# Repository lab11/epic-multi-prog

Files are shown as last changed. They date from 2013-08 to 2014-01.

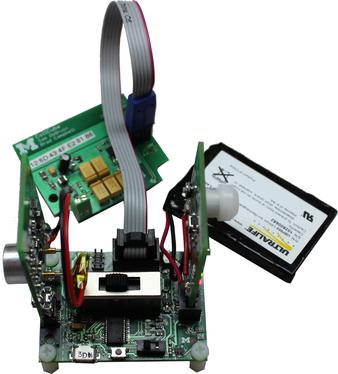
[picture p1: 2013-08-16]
media/epic_multi_prog_connected_338x374.jpg

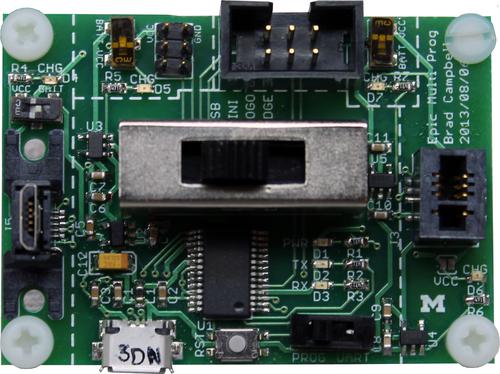
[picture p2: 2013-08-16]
media/epic_multi_prog_500x374.jpg

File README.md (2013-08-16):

Epic Multi Prog
===============

emp (https://raw.github.com/lab11/epic-multi-prog/master/media/epic_multi_prog.jpg)
emp_connected (https://raw.github.com/lab11/epic-multi-prog/master/media/epic_multi_prog_connected.jpg)

Programmer hardware for programming the epic family of devices.
Over the years many different physical connections for programming the epic chip have
been created. This programmer tries to support the common ones:

- Edge style: as used by the Irene family of sensor nodes
- Tag connect (pogo pins): new 6-pin connector from Tag Connect
- Mini prog: 6 pin 2mm connector as used by some epic devices
- Pseudo USB: micro USB connector that also uses the shield for some epic devices

All connection types have their own charging module and charging LED. The center switch
selects which header is connected to the programming lines and therefore which one should
be programmed. The board connects to a computer via a micro USB cable.

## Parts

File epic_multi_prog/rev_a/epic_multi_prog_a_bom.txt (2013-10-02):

# Bill of Materials
# Converted from epic_multi_prog_a_bom.xls
# Generated by bom_to_text.py

Qty  Value                              Device                             Package                            Parts                             Description                                            DIGIKEY            MOUSER         DIGIREEL
3    0.1u                               C-EUC0603                          C0603                              C1, C2, C3                        CAPACITOR, European symbol                             445-1316-1-ND                     445-1316-6-ND
8    1u                                 C-EUC0603                          C0603                              C4, C5, C6, C7, C8, C9, C10, C11  CAPACITOR, European symbol                             445-1321-1-ND                     445-1321-6-ND
1    10u                                CAP_POL1206                        EIA3216                            C12                               Capacitor Polarized                                    478-1655-1-ND                     478-1655-6-ND
1    BLUE                               LED0603                            LED-0603                           D1                                LEDs                                                   160-1837-1-ND                     160-1837-6-ND
1    RED                                LED0603                            LED-0603                           D2                                LEDs                                                   160-1835-1-ND                     160-1835-6-ND
1    GREEN                              LED0603                            LED-0603                           D3                                LEDs                                                   160-1834-1-ND                     160-1834-6-ND
4    YELLOW                             LED0603                            LED-0603                           D4, D5, D6, D7                    LEDs                                                   160-1184-1-ND                     160-1184-6-ND
1    EPIC-PROG-PORT                     EPIC-PROG-PORT                     HEADER2X3X2MM                      J1                                                                                       3M9173-ND                         
1    MICRO_USB_B_HIROSE_ZX62R-B-5P      MICRO_USB_B_HIROSE_ZX62R-B-5P      USB_MICRO_B-HIROSE-ZX62R-B-5P      J2                                USB Micro B Connector                                  H11574CT-ND                       H11574DKR-ND
1    MEC1-105-02-XX-XX-D-A              MEC1-105-02-XX-XX-D-A              MEC1-105-02-XX-XX-D-A              J3                                                                                       SAM8115-ND                        
1    TAG_CONNECT_HEADER_EPIC            TAG_CONNECT_HEADER_EPIC            2X3_MALE_SHROUDED_0.100            J4                                2x3 Male Shrouded Header 0.100                         3M15451-ND                        
1    MICRO_USB_B_MALE_HIROSE_ZX80-B-5S  MICRO_USB_B_MALE_HIROSE_ZX80-B-5S  USB_MICRO_B_MALE-HIROSE-ZX80-B-5S  J5                                CONN PLUG MCR USB B PCB VERT                           H11612-ND          798-ZX80-B-5S  
1                                       INDUCTOR0603                       603                                L1                                Inductors                                              240-2373-1-ND                     240-2373-6-ND
7    470                                R-US_R0603                         R0603                              R1, R2, R3, R4, R5, R6, R7        RESISTOR, American symbol                              P470GDKR-ND                       P470GDKR-ND
1    TE_SSA12/SPDT                      TE_SSA12/SPDT                      TE_SSA12/SPDT                      S1                                SWITCH SLIDE SPDT 2POS SSA SER                         450-1602-ND                       
1    CK_SS-44D04-G4/4P4T                CK_SS-44D04-G4/4P4T                CK_SS-44D04-G4/4P4T                S2                                Through hole 4P4T switch.                              CKN10389-ND                       
1    EVQP2                              EVQP2                              EVQP2                              S3                                                                                       P11084SCT-ND                      
3    COPAL_CJS-1200TA/SPDT              COPAL_CJS-1200TA/SPDT              COPAL_CJS-1200TA/SPDT              S4, S5, S6                        SWITCH SLIDE SPDT SMD J-LEAD                           563-1021-2-ND                     563-1021-6-ND
1    FT232RL                            FT232RL                            SSOP28                             U1                                FTDI chip                                              768-1007-1-ND                     768-1007-6-ND
4    MAX1555                            MAX1555                            SOT23-5L                           U2, U3, U4, U5                    Dual-Input USB/AC Adapter 1-Cell Li+ Battery Chargers  MAX1555EZK+TCT-ND                 MAX1555EZK+TDKR-ND

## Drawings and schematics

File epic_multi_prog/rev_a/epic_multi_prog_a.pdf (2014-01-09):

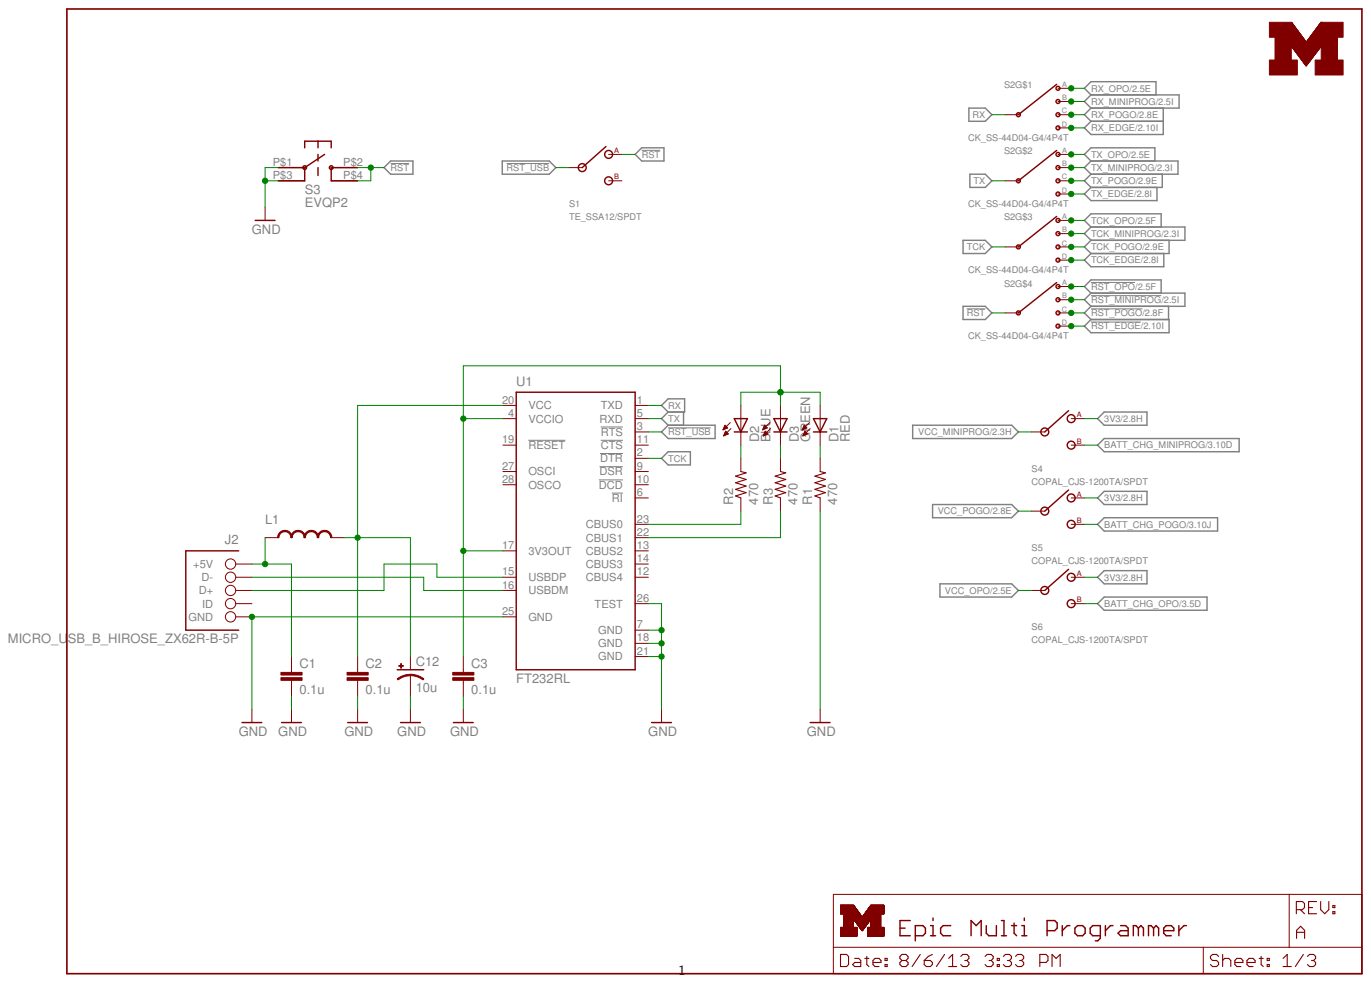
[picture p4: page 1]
GND 0.1u; 0.1u GND GND; GND; 470 BLUE; GREEN EVQP2 GND; RED 470 GND; CK_SS-44D04-G4/4P4T CK_SS-44D04-G4/4P4T CK_SS-44D04-G4/4P4T CK_SS-44D04-G4/4P4T COPAL_CJS-1200TA/SPDT COPAL_CJS-1200TA/SPDT COPAL_CJS-1200TA/SPDT TE_SSA12/SPDT U1VCC 20; 3V3OUT 17; USBDP 15; USBDM 16; OSCO 28; OSCI 27; 7 TXD; 1 RXD; 5 RTS; 3 CTS; 11 DTR; 2 DSR; 9 DCD; 6 CBUS0; 23 CBUS1; 22 CBUS2; 13 CBUS3; 14 CBUS4; 12 VCCIO 4; RESET 19; GND 25; 18 TEST; 26 GND; P$4 J2 MICRO_USB_B_HIROSE_ZX62R-B-5P ⁺⁵VD- D+ID GND; ABCD S2G$1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

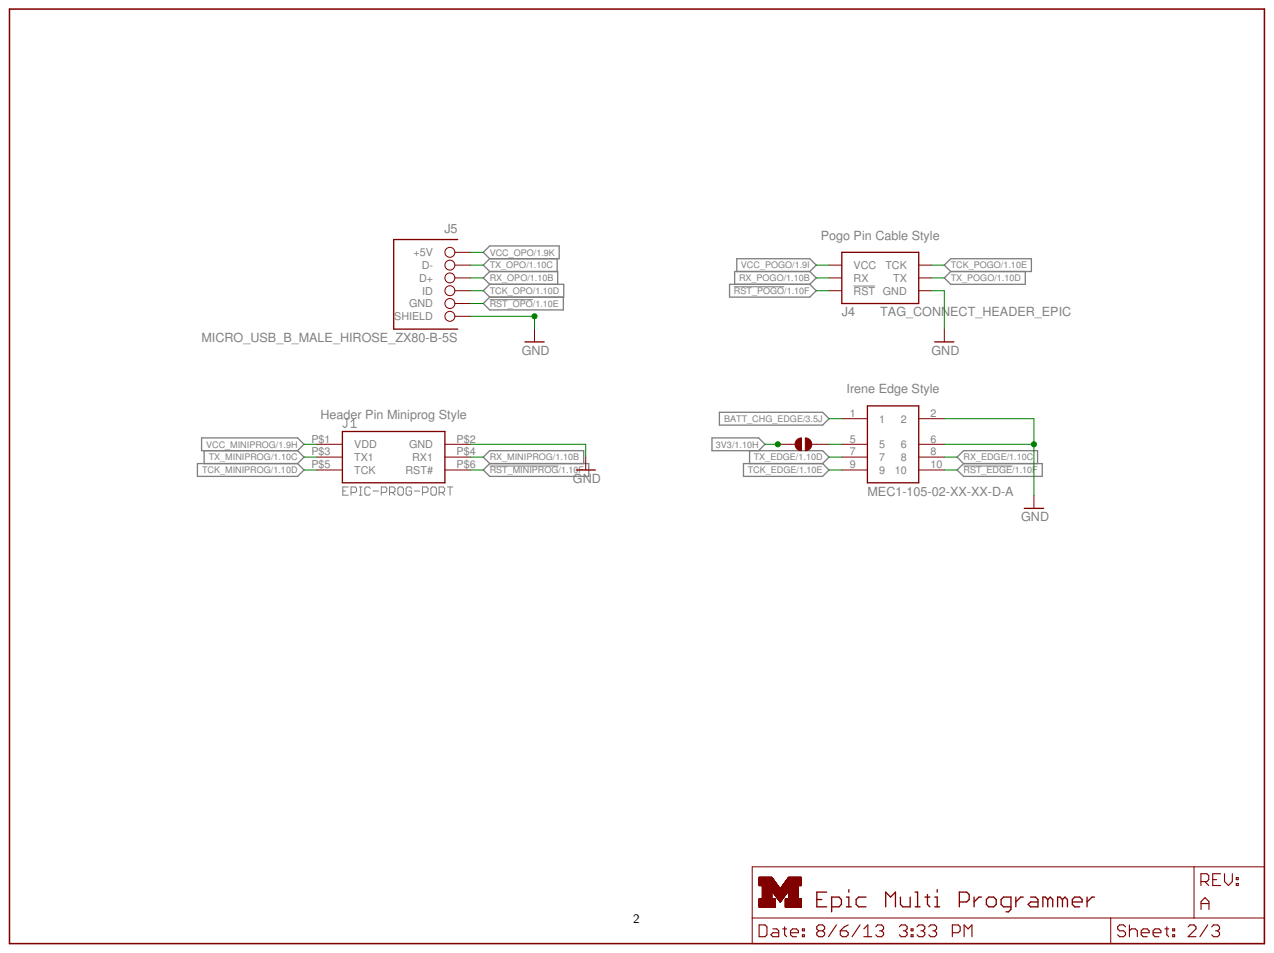
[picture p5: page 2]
MEC1-105-02-XX-XX-D-A; GND; TAG_CONNECT_HEADER_EPIC; VDD; P$1 TX1 P$3 TCK; RST#; P$4 GND; VCC RX RST; TCK TX GND; MICRO_USB_B_MALE_HIROSE_ZX80-B-5S; ID GND SHIELD; TX_MINIPROG/1.10C; TX_EDGE/1.10D; TX_POGO/1.10D; TX_OPO/1.10C; RX_OPO/1.10B; RX_POGO/1.10B; RX_MINIPROG/1.10B; RX_EDGE/1.10C; RST_OPO/1.10E; TCK_MINIPROG/1.10D; TCK_EDGE/1.10E; TCK_POGO/1.10E; TCK_OPO/1.10D; RST_MINIPROG/1.10F; RST_EDGE/1.10F; RST_POGO/1.10F VCC_OPO/1.9K VCC_POGO/1.9I; VCC_MINIPROG/1.9H; BATT_CHG_EDGE/3.5J

Pogo Pin Cable Style

Irene Edge Style Header Pin Miniprog Style

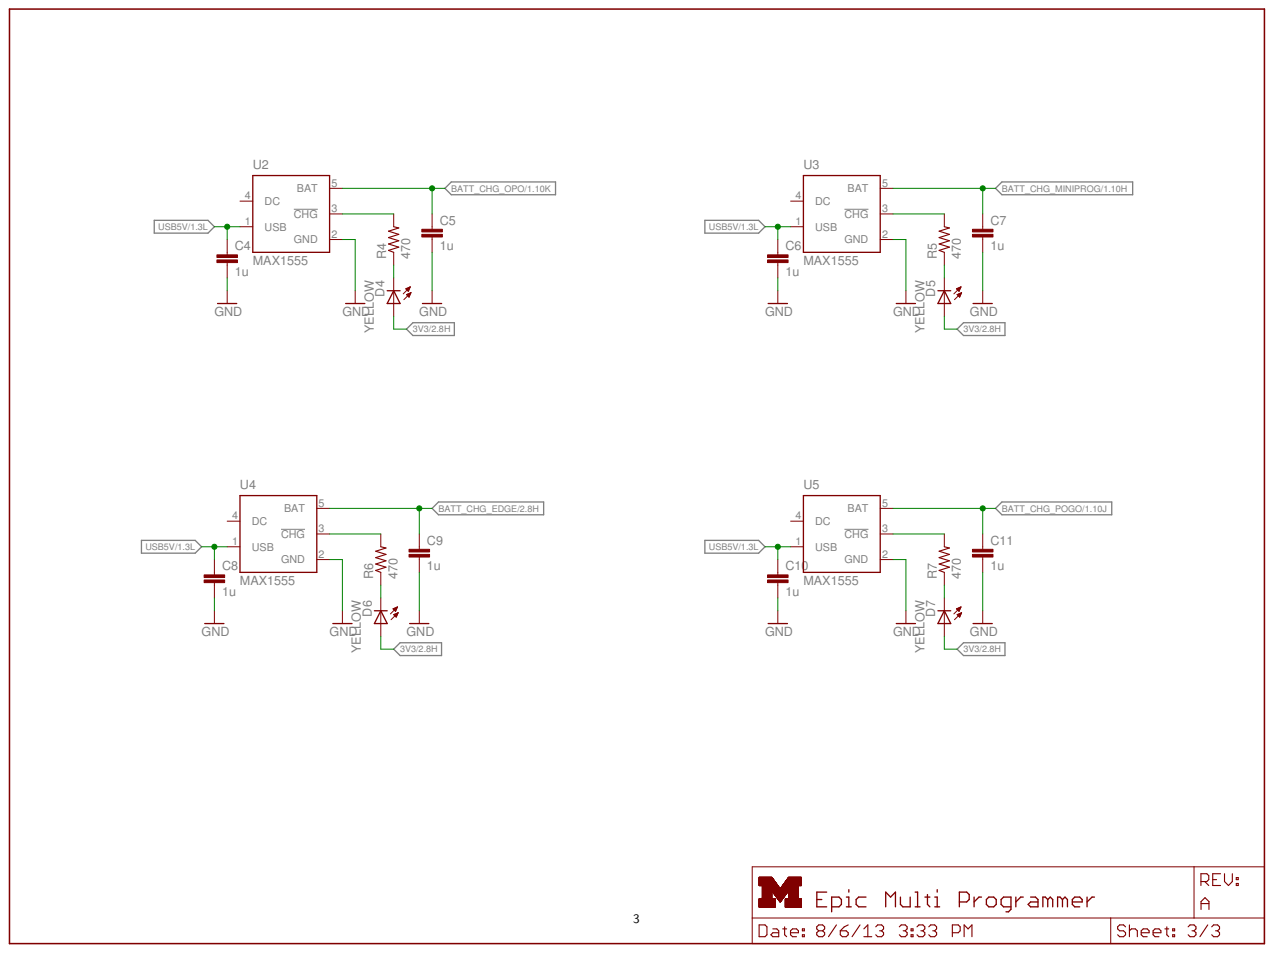
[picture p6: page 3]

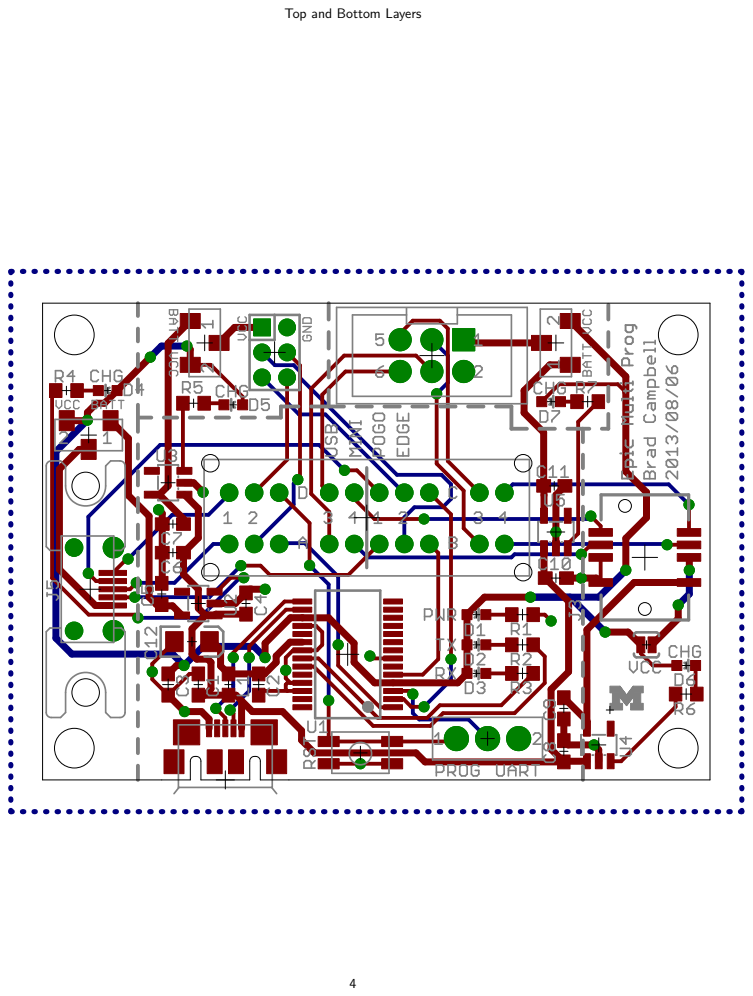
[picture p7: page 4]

Top and Bottom Layers

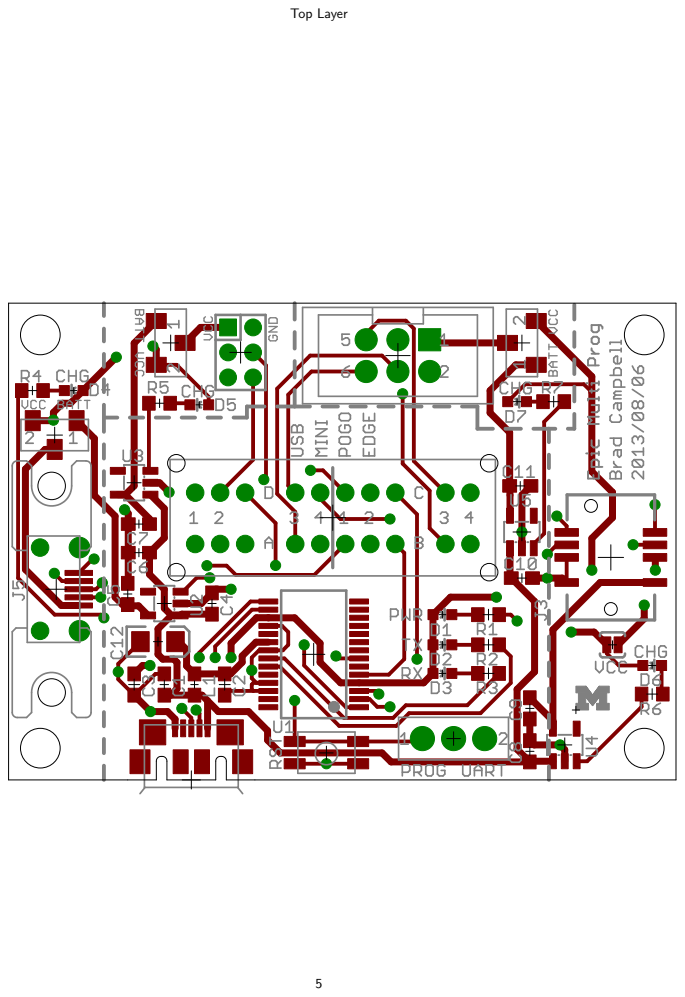
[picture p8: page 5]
Top Layer

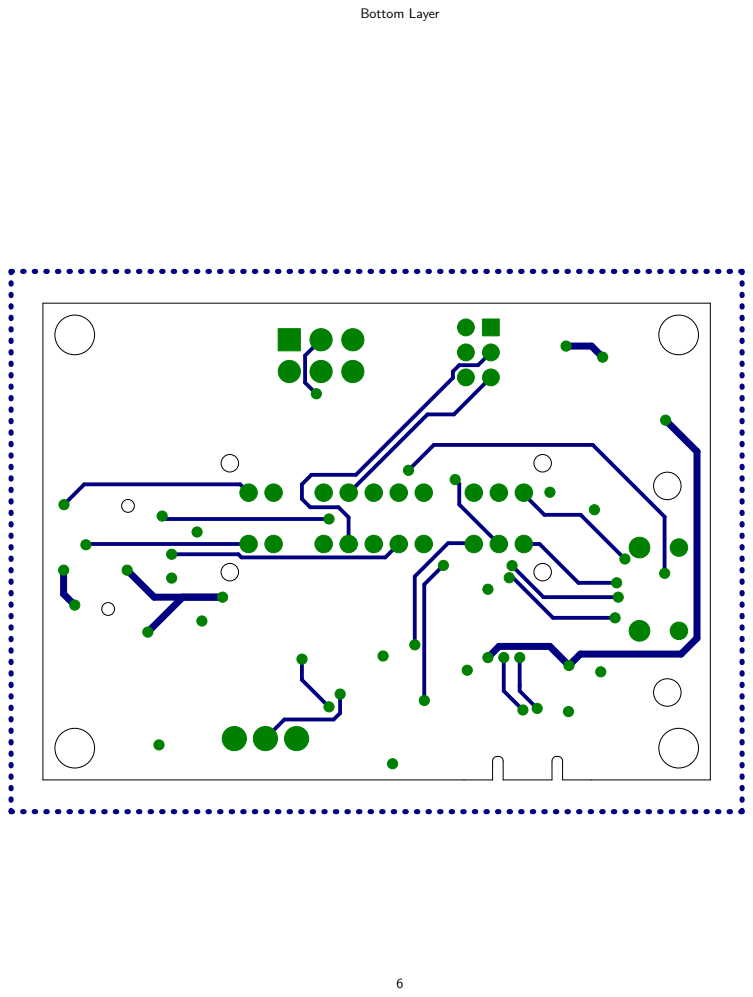
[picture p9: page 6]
Bottom Layer

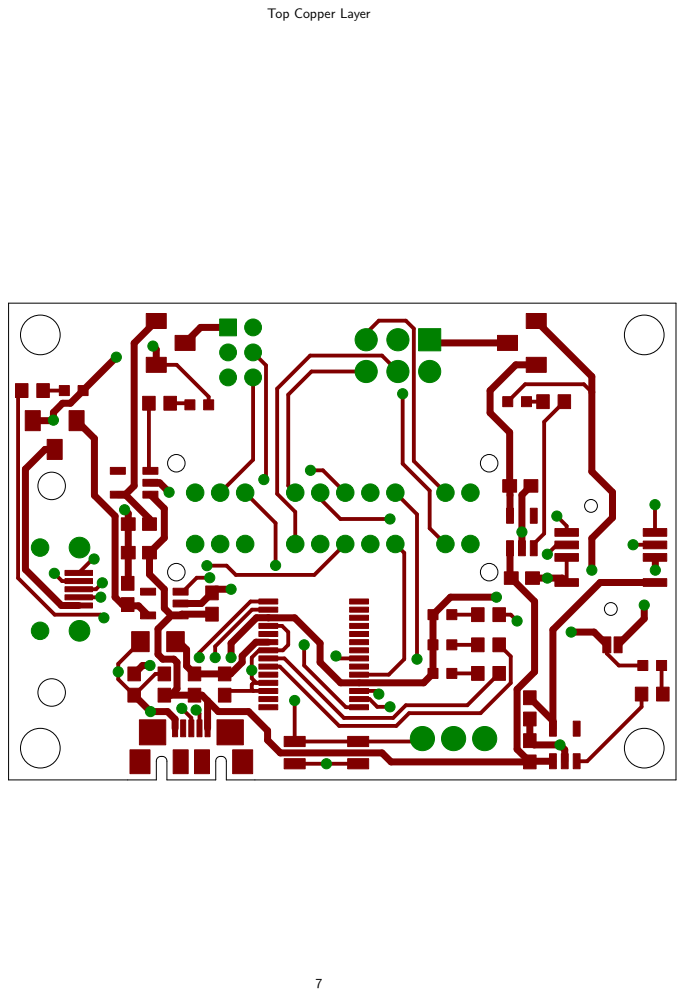
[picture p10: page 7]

Top Copper Layer

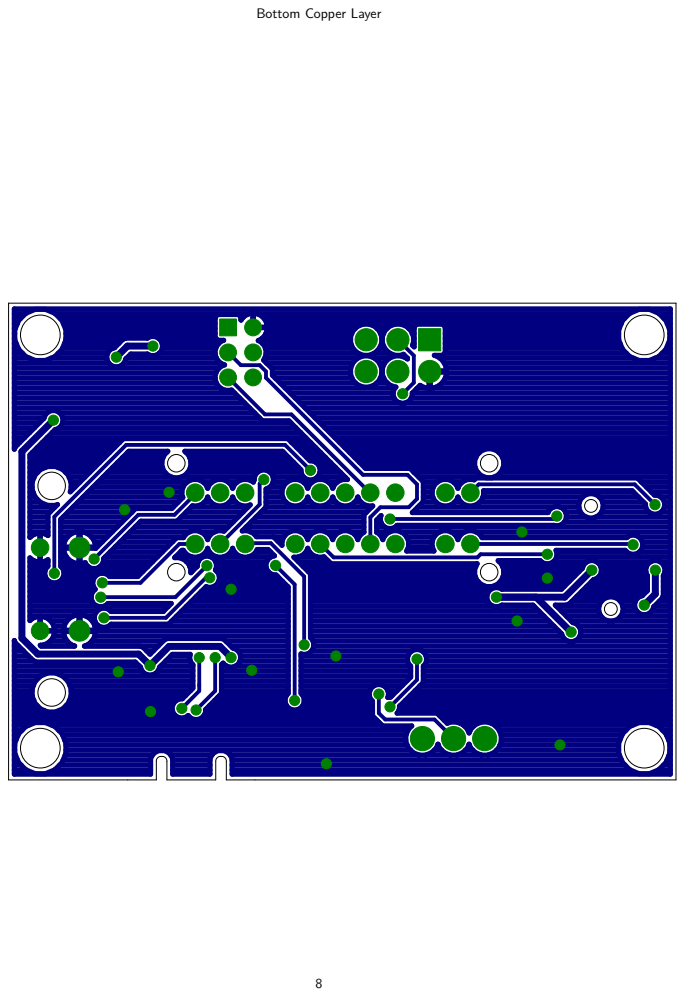
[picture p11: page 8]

Bottom Copper Layer

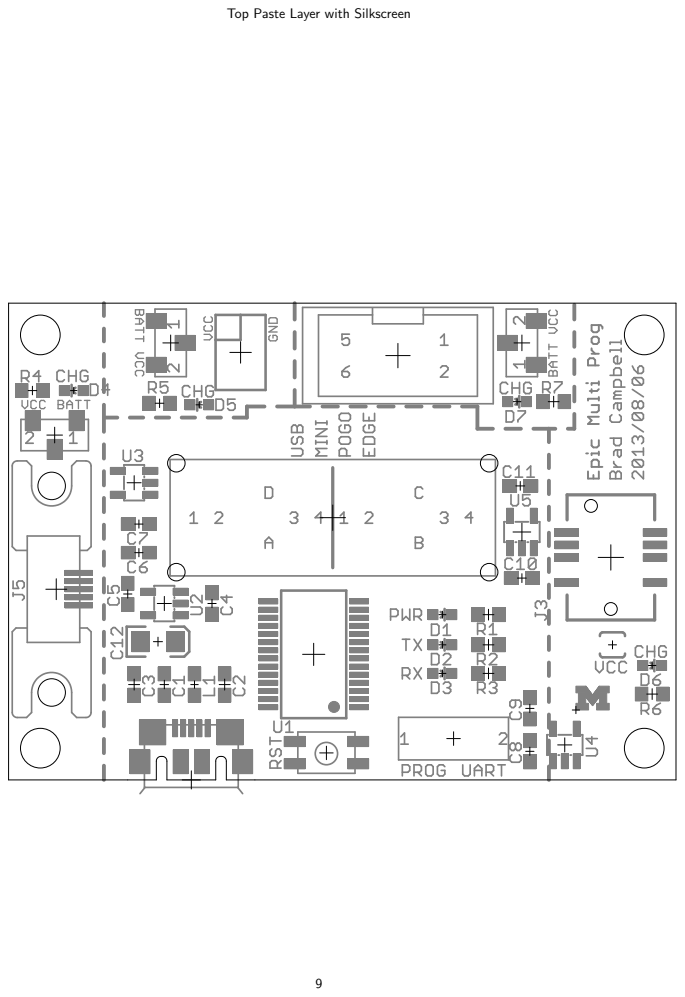
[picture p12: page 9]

Top Paste Layer with Silkscreen

Bottom Paste Layer with Silkscreen

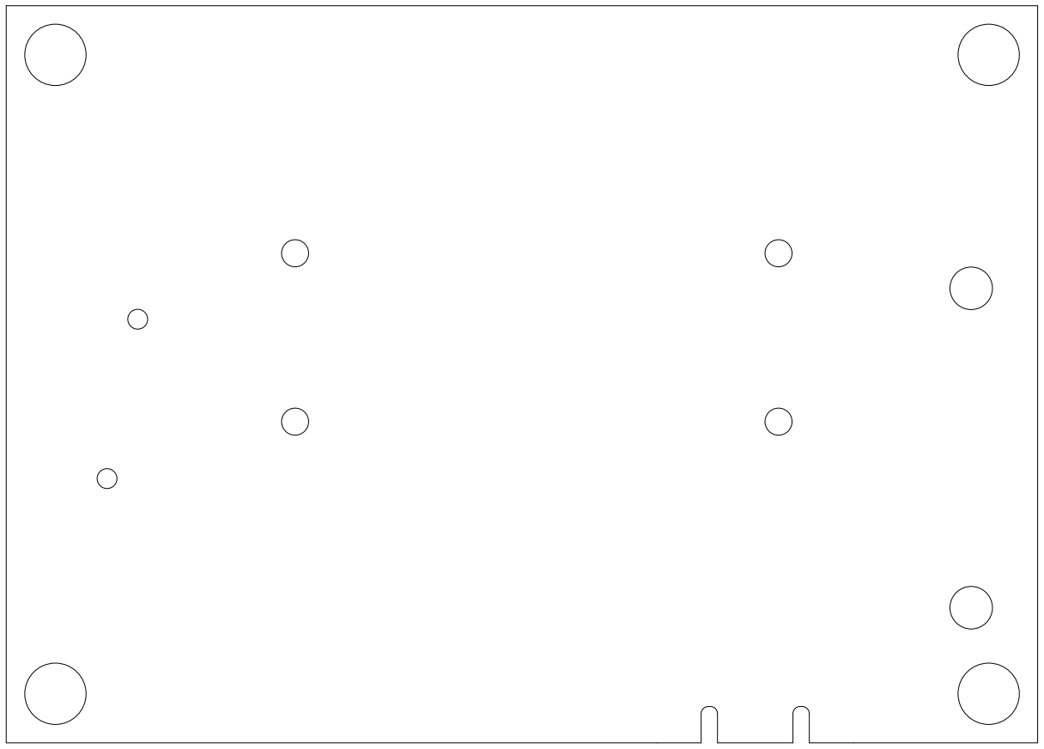
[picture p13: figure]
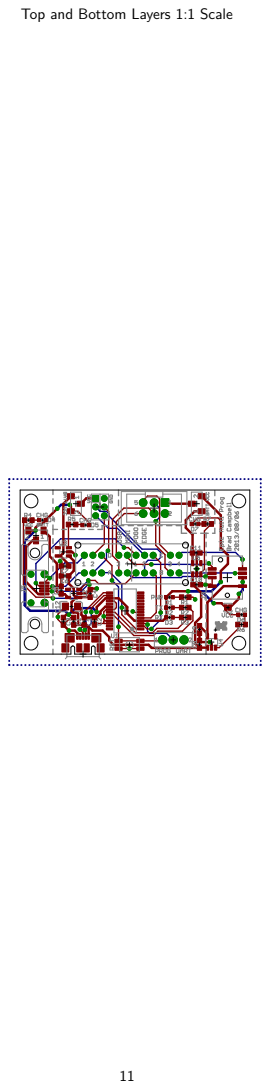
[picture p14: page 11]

Top and Bottom Layers 1:1 Scale

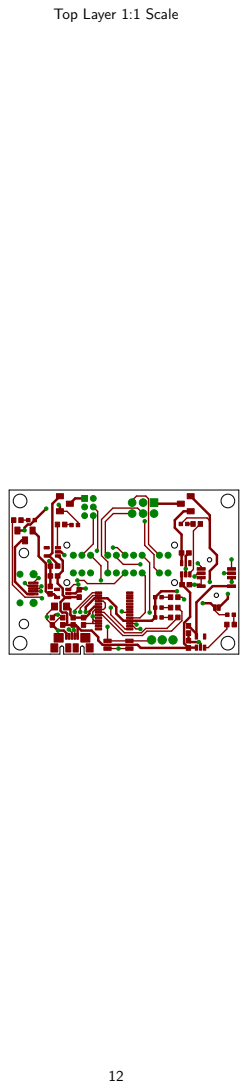
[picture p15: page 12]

Top Layer 1:1 Scale


Bottom Copper Layer 1:1 Scale

### Sheet1

Qty Value | Device
3 0.1u | C-EUC0603
8 1u | C-EUC0603
1 10u | CAP_POL1206
1 BLUE | LED0603
1 RED | LED0603
1 GREEN | LED0603
4 YELLOW | LED0603
1 EPIC-PROG-PORT | EPIC-PROG-PORT
1 MICRO_USB_B_HIROSE_ZX62R-B-5P | MICRO_USB_B_HIROSE_ZX62R-B-5P
1 MEC1-105-02-XX-XX-D-A | MEC1-105-02-XX-XX-D-A
1 TAG_CONNECT_HEADER_EPIC | TAG_CONNECT_HEADER_EPIC
1 MICRO_USB_B_MALE_HIROSE_ZX80-B-5S MICRO_USB_B_MALE_HIROSE_ZX80-B-5S
1 | INDUCTOR0603
7 470 | R-US_R0603
1 TE_SSA12/SPDT | TE_SSA12/SPDT
1 CK_SS-44D04-G4/4P4T | CK_SS-44D04-G4/4P4T
1 EVQP2 | EVQP2
3 COPAL_CJS-1200TA/SPDT | COPAL_CJS-1200TA/SPDT
1 FT232RL | FT232RL
4 MAX1555 | MAX1555

### Sheet1

Package | Parts
C0603 | C1, C2, C3
C0603 | C4, C5, C6, C7, C8, C9, C10, C11
EIA3216 | C12
LED-0603 | D1
LED-0603 | D2
LED-0603 | D3
LED-0603 | D4, D5, D6, D7
HEADER2X3X2MM | J1
USB_MICRO_B-HIROSE-ZX62R-B-5P | J2
MEC1-105-02-XX-XX-D-A | J3
2X3_MALE_SHROUDED_0.100 | J4
USB_MICRO_B_MALE-HIROSE-ZX80-B-5S J5
603 | L1
R0603 | R1, R2, R3, R4, R5, R6, R7
TE_SSA12/SPDT | S1
CK_SS-44D04-G4/4P4T | S2
EVQP2 | S3
COPAL_CJS-1200TA/SPDT | S4, S5, S6
SSOP28 | U1
SOT23-5L | U2, U3, U4, U5

### Sheet1

Description | DIGIKEY | MOUSER
CAPACITOR, European symbol | 445-1316-1-ND
CAPACITOR, European symbol | 445-1321-1-ND
Capacitor Polarized | 478-1655-1-ND
LEDs | 160-1837-1-ND
LEDs | 160-1835-1-ND
LEDs | 160-1834-1-ND
LEDs | 160-1184-1-ND
| 3M9173-ND
USB Micro B Connector | H11574CT-ND
| SAM8115-ND
2x3 Male Shrouded Header 0.100 | 3M15451-ND
CONN PLUG MCR USB B PCB VERT | H11612-ND | 798-ZX80-B-5S
Inductors | 240-2373-1-ND
RESISTOR, American symbol | P470GDKR-ND
SWITCH SLIDE SPDT 2POS SSA SER | 450-1602-ND
Through hole 4P4T switch. | CKN10389-ND
| P11084SCT-ND
SWITCH SLIDE SPDT SMD J-LEAD | 563-1021-2-ND
FTDI chip | 768-1007-1-ND
Dual-Input USB/AC Adapter 1-Cell Li+ Battery Chargers MAX1555EZK+TCT-ND

### Sheet1

DIGIREEL
445-1316-6-ND
445-1321-6-ND
478-1655-6-ND
160-1837-6-ND
160-1835-6-ND
160-1834-6-ND
160-1184-6-ND

H11574DKR-ND

240-2373-6-ND
P470GDKR-ND

563-1021-6-ND
768-1007-6-ND
MAX1555EZK+TDKR-ND

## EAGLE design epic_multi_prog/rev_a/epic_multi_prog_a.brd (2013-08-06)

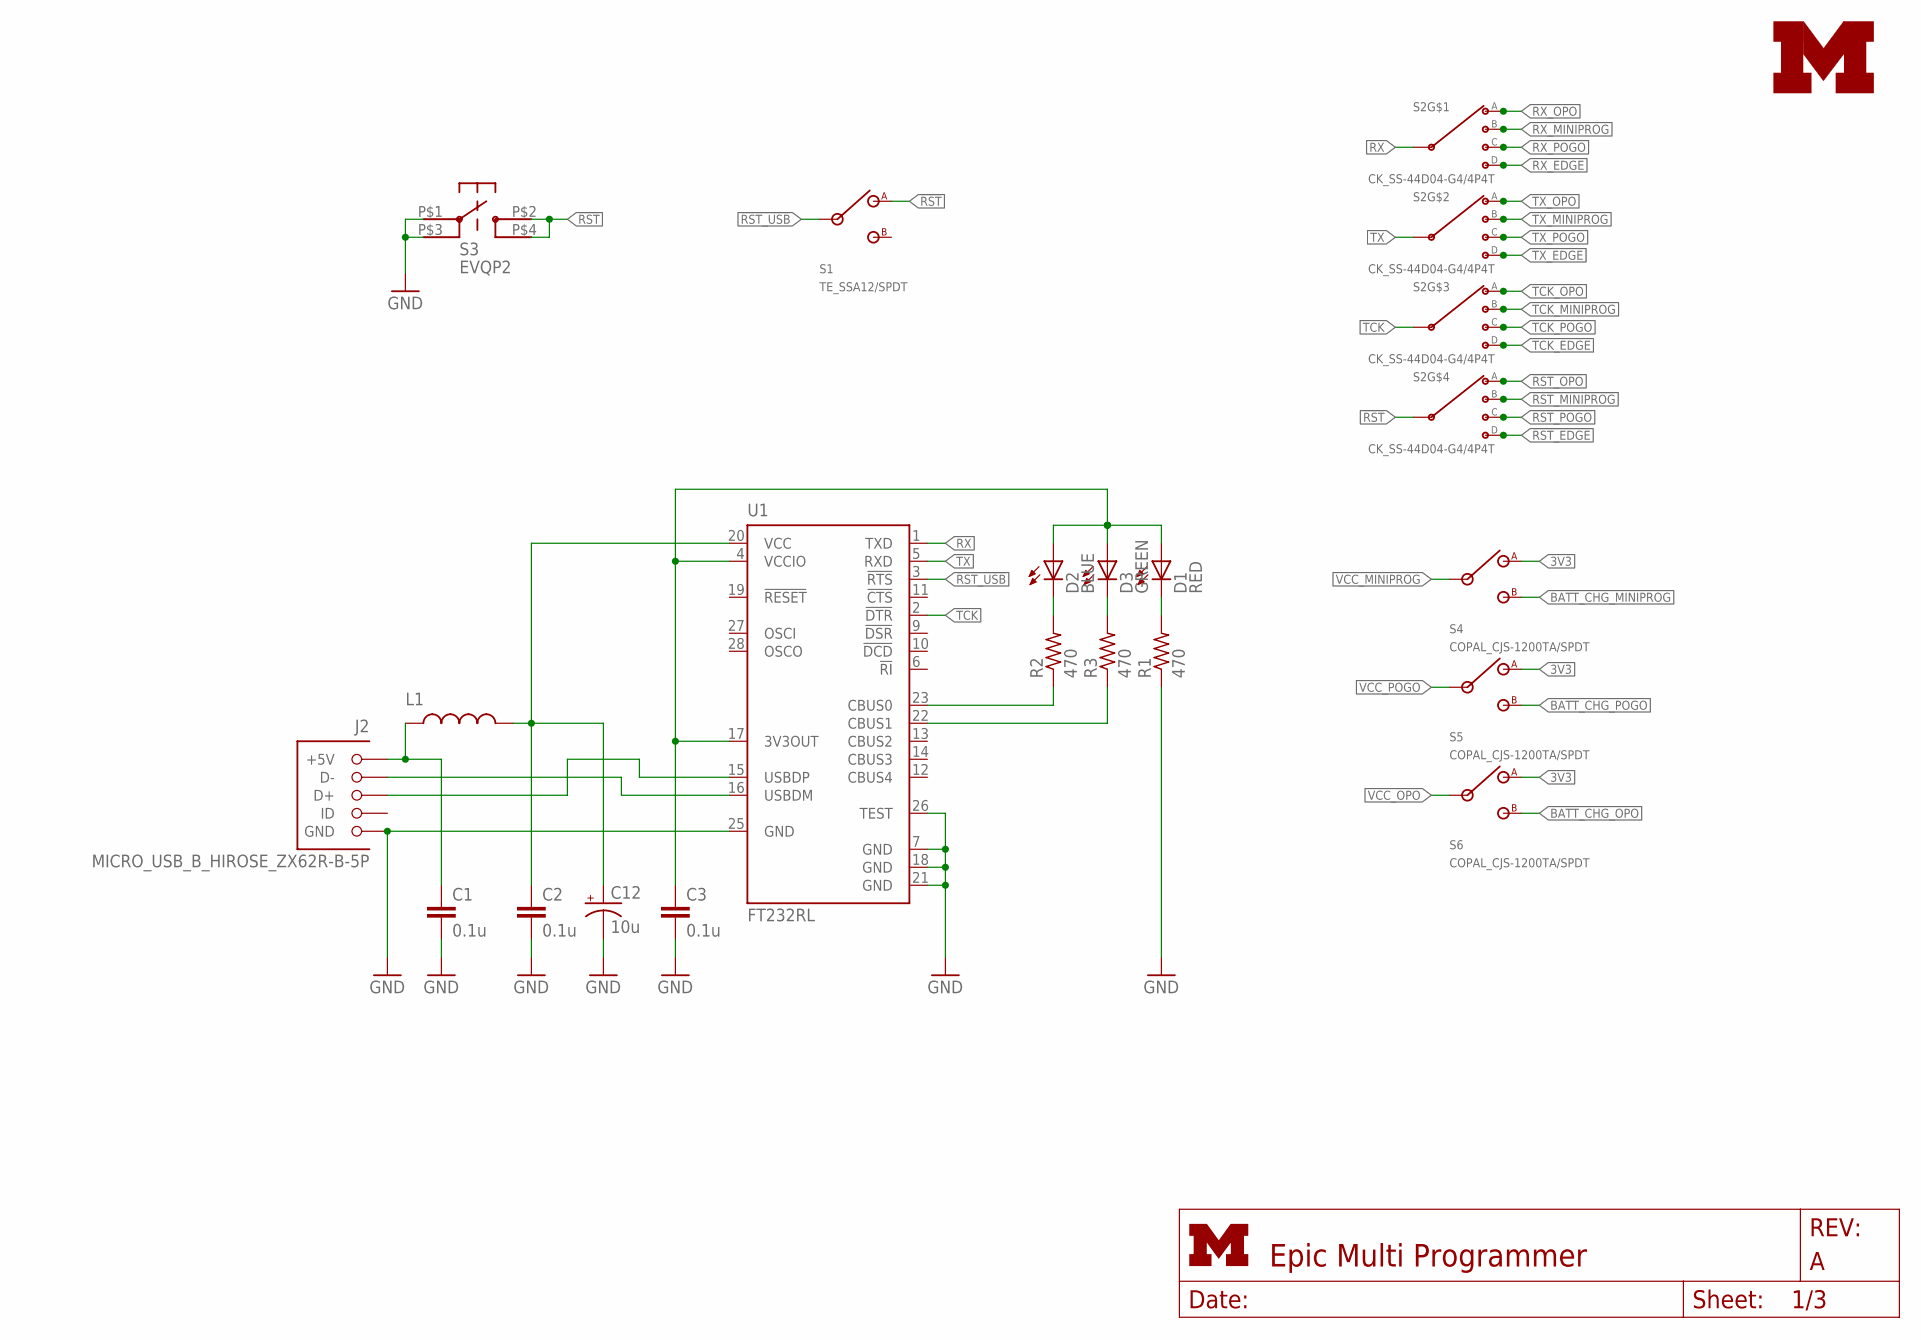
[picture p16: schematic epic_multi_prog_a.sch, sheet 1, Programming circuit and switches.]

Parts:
C1, C2, C3: 0.1u; C0603; DIGIKEY 445-1316-1-ND
C12: 10u; EIA3216; DIGIKEY 478-1655-1-ND
D1: RED; LED-0603
D2: BLUE; LED-0603
D3: GREEN; LED-0603
J2: MICRO_USB_B_HIROSE_ZX62R-B-5P; USB_MICRO_B-HIROSE-ZX62R-B-5P
L1: INDUCTOR0603; 0603; DIGIKEY 240-2373-1-ND
R1, R2, R3: 470; R0603
S1: TE_SSA12/SPDT
S2: CK_SS-44D04-G4/4P4T; DIGIKEY CKN10389-ND
S3: EVQP2; DIGIKEY P11084SCT-ND
S4, S5, S6: COPAL_CJS-1200TA/SPDT
U1: FT232RL; SSOP28; DIGIKEY 768-1007-1-ND
U$1: UMICH_SOLID_SMALL; UMICH_SOLID_75MIL

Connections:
3V3: C3.1, D1.A, D2.A, D3.A, S4.2 (A), S5.2 (A), S6.2 (A), U1.4 (VCCIO), U1.17 (3V3OUT); also elsewhere on the board
!RST: S1.1 (A), S2.IND (INPUT), S3.P$2, S3.P$4
!RST_EDGE: S2.D4 (D); also elsewhere on the board
!RST_MINIPROG: S2.D2 (B); also elsewhere on the board
!RST_OPO: S2.D1 (A); also elsewhere on the board
!RST_POGO: S2.D3 (C); also elsewhere on the board
!RST_USB: S1.IN, U1.3 (!RTS)
BATT_CHG_MINIPROG: S4.1 (B); also elsewhere on the board
BATT_CHG_OPO: S6.1 (B); also elsewhere on the board
BATT_CHG_POGO: S5.1 (B); also elsewhere on the board
GND: C1.2, C2.2, C3.2, C12.C (-), J2.5 (GND), R1.1, S3.P$1, S3.P$3, U1.7 (GND), U1.18 (GND), U1.21 (GND), U1.25 (GND), U1.26 (TEST); also elsewhere on the board
unnamed: D2.C, R2.2
unnamed: J2.2 (D-), U1.16 (USBDM)
unnamed: J2.3 (D+), U1.15 (USBDP)
unnamed: C2.1, C12.A (+), L1.2, U1.20 (VCC)
unnamed: D3.C, R3.2
unnamed: D1.C, R1.2
unnamed: R2.1, U1.23 (CBUS0)
unnamed: R3.1, U1.22 (CBUS1)
RX: S2.INA (INPUT), U1.1 (TXD)
RX_EDGE: S2.A4 (D); also elsewhere on the board
RX_MINIPROG: S2.A2 (B); also elsewhere on the board
RX_OPO: S2.A1 (A); also elsewhere on the board
RX_POGO: S2.A3 (C); also elsewhere on the board
TCK: S2.INC (INPUT), U1.2 (!DTR)
TCK_EDGE: S2.C4 (D); also elsewhere on the board
TCK_MINIPROG: S2.C2 (B); also elsewhere on the board
TCK_OPO: S2.C1 (A); also elsewhere on the board
TCK_POGO: S2.C3 (C); also elsewhere on the board
TX: S2.INB (INPUT), U1.5 (RXD)
TX_EDGE: S2.B4 (D); also elsewhere on the board
TX_MINIPROG: S2.B2 (B); also elsewhere on the board
TX_OPO: S2.B1 (A); also elsewhere on the board
TX_POGO: S2.B3 (C); also elsewhere on the board
USB5V: C1.1, J2.1 (+5V), L1.1; also elsewhere on the board
VCC_MINIPROG: S4.IN; also elsewhere on the board
VCC_OPO: S6.IN; also elsewhere on the board
VCC_POGO: S5.IN; also elsewhere on the board

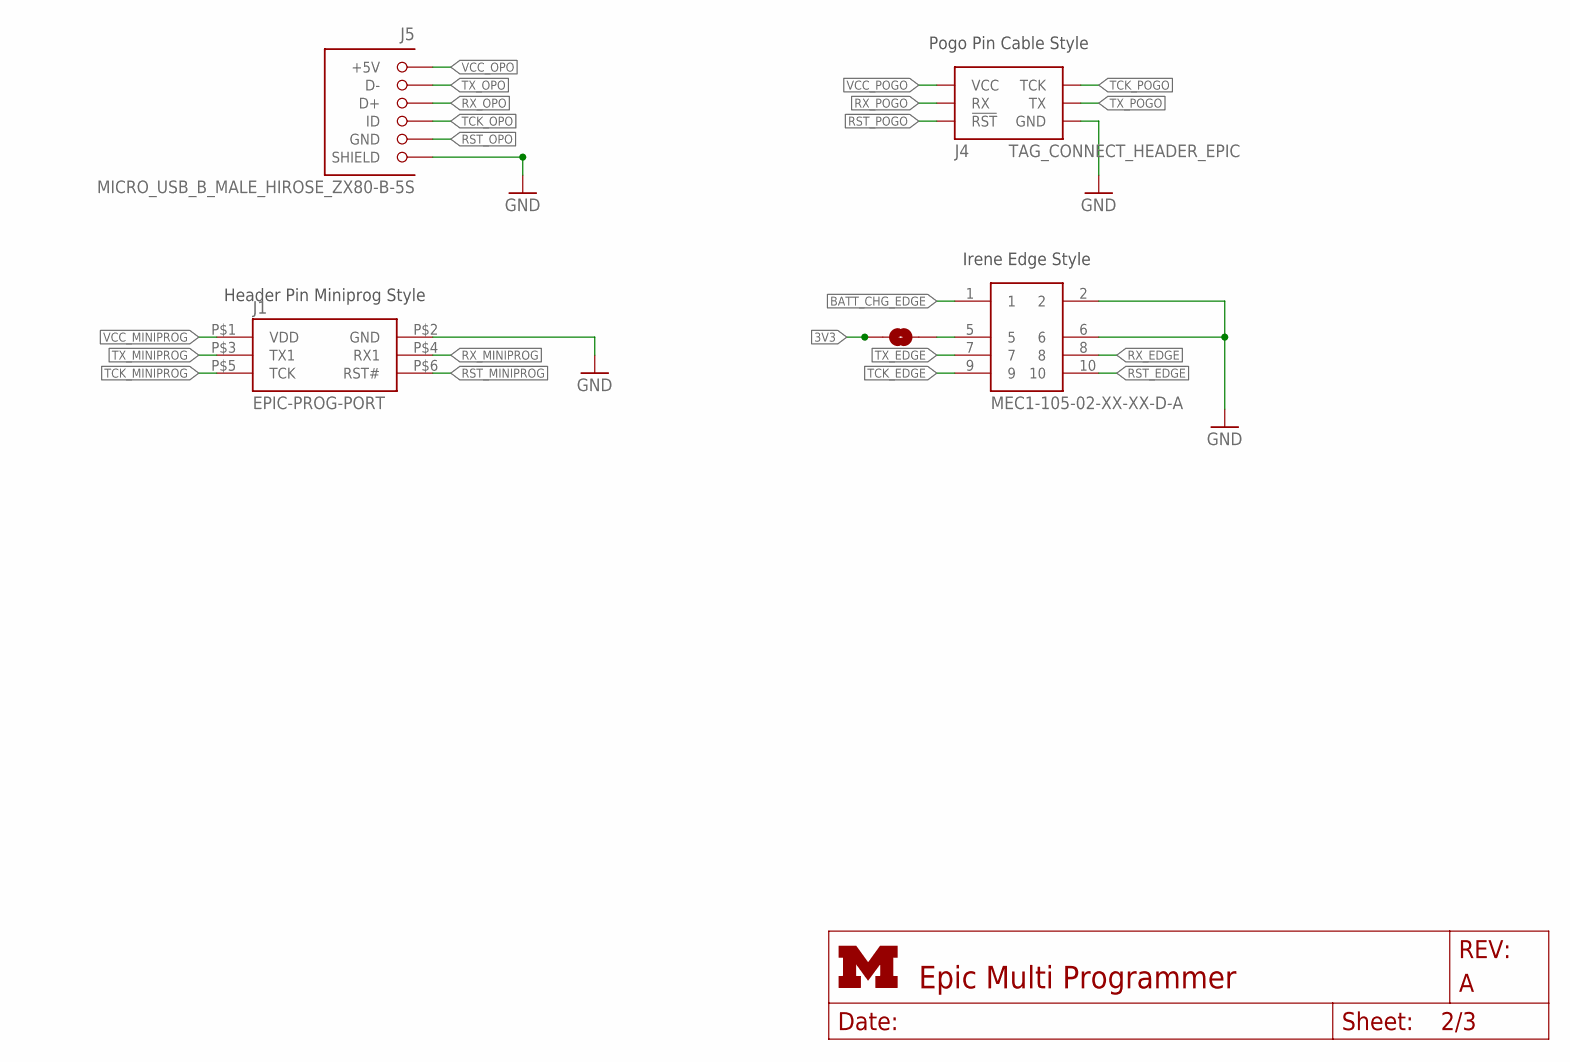
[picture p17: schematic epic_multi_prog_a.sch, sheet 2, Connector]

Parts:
J1: EPIC-PROG-PORT; HEADER2X3X2MM
J3: MEC1-105-02-XX-XX-D-A; DIGIKEY SAM8115-ND
J4: TAG_CONNECT_HEADER_EPIC; 2X3_MALE_SHROUDED_0.100
J5: MICRO_USB_B_MALE_HIROSE_ZX80-B-5S; USB_MICRO_B_MALE-HIROSE-ZX80-B-5S; MOUSER 798-ZX80-B-5S
SJ1: SOLDERJUMPERNO; SJ_2S-NO

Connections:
3V3: SJ1.1; also elsewhere on the board
!RST_EDGE: J3.10; also elsewhere on the board
!RST_MINIPROG: J1.P$6 (RST#); also elsewhere on the board
!RST_OPO: J5.5 (GND); also elsewhere on the board
!RST_POGO: J4.6 (!RST); also elsewhere on the board
BATT_CHG_EDGE: J3.1; also elsewhere on the board
GND: J1.P$2 (GND), J3.2, J3.6, J4.2 (GND), J5.SHIELD1 (SHIELD), J5.SHIELD2 (SHIELD), J5.SHIELD3 (SHIELD), J5.SHIELD4 (SHIELD); also elsewhere on the board
unnamed: J3.5, SJ1.2
RX_EDGE: J3.8; also elsewhere on the board
RX_MINIPROG: J1.P$4 (RX1); also elsewhere on the board
RX_OPO: J5.3 (D+); also elsewhere on the board
RX_POGO: J4.4 (RX); also elsewhere on the board
TCK_EDGE: J3.9; also elsewhere on the board
TCK_MINIPROG: J1.P$5 (TCK); also elsewhere on the board
TCK_OPO: J5.4 (ID); also elsewhere on the board
TCK_POGO: J4.5 (TCK); also elsewhere on the board
TX_EDGE: J3.7; also elsewhere on the board
TX_MINIPROG: J1.P$3 (TX1); also elsewhere on the board
TX_OPO: J5.2 (D-); also elsewhere on the board
TX_POGO: J4.3 (TX); also elsewhere on the board
VCC_MINIPROG: J1.P$1 (VDD); also elsewhere on the board
VCC_OPO: J5.1 (+5V); also elsewhere on the board
VCC_POGO: J4.1 (VCC); also elsewhere on the board

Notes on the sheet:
Irene Edge Style
Header Pin Miniprog Style
Pogo Pin Cable Style

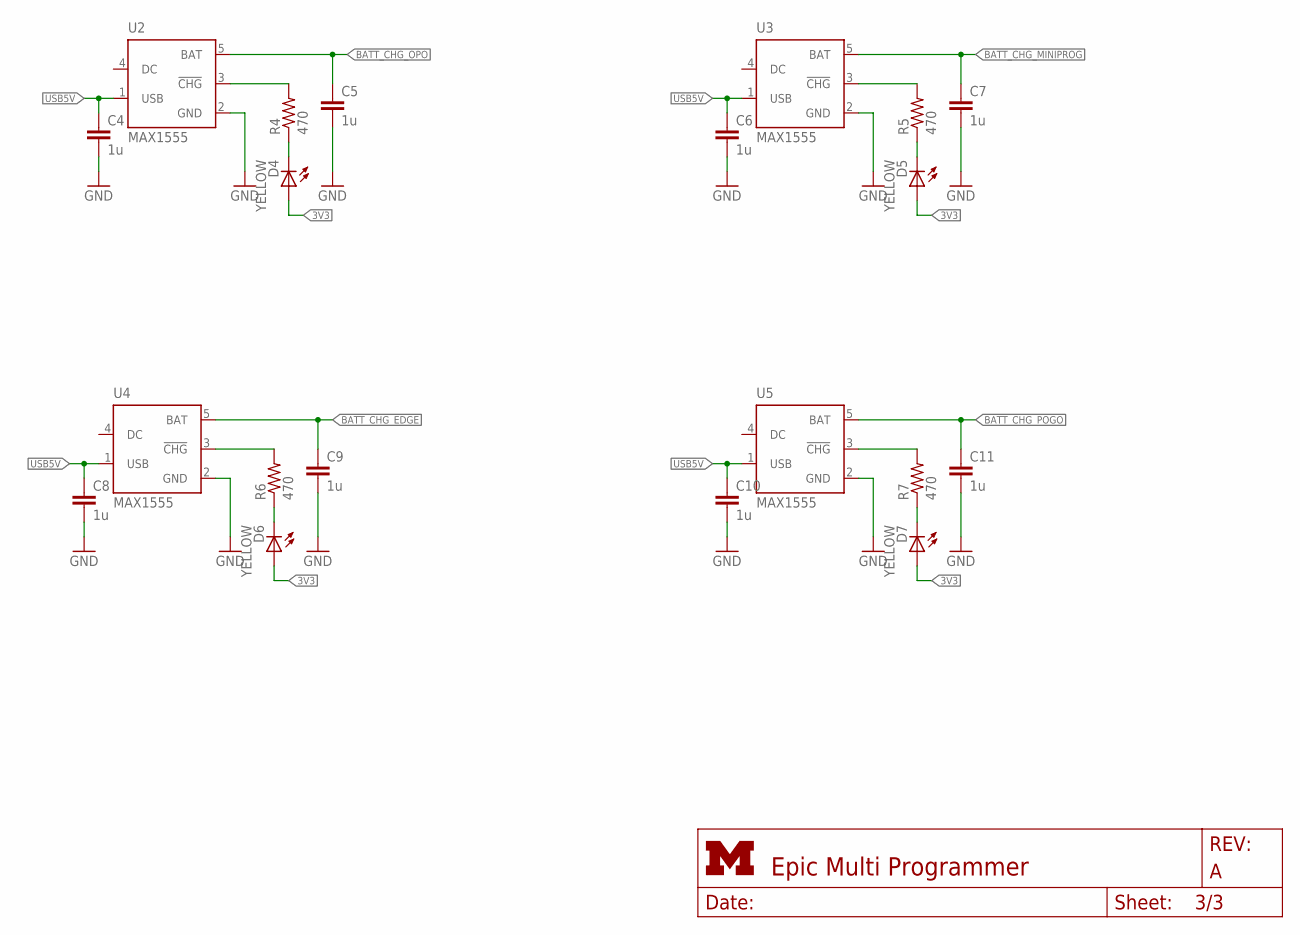
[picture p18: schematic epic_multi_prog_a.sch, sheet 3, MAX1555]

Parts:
C4, C5, C6, C7, C8, C9, C10, C11: 1u; C0603; DIGIKEY 445-1321-1-ND
D4, D5, D6, D7: YELLOW; LED-0603
R4, R5, R6, R7: 470; R0603
U2, U3, U4, U5: MAX1555; SOT23-5L; DIGIKEY MAX1555EZK+TCT-ND

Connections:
3V3: D4.A, D5.A, D6.A, D7.A; also elsewhere on the board
BATT_CHG_EDGE: C9.1, U4.5 (BAT); also elsewhere on the board
BATT_CHG_MINIPROG: C7.1, U3.5 (BAT); also elsewhere on the board
BATT_CHG_OPO: C5.1, U2.5 (BAT); also elsewhere on the board
BATT_CHG_POGO: C11.1, U5.5 (BAT); also elsewhere on the board
GND: C4.2, C5.2, C6.2, C7.2, C8.2, C9.2, C10.2, C11.2, U2.2 (GND), U3.2 (GND), U4.2 (GND), U5.2 (GND); also elsewhere on the board
unnamed: D5.C, R5.1
unnamed: D4.C, R4.1
unnamed: R4.2, U2.3 (!CHG)
unnamed: R5.2, U3.3 (!CHG)
unnamed: D6.C, R6.1
unnamed: R6.2, U4.3 (!CHG)
unnamed: D7.C, R7.1
unnamed: R7.2, U5.3 (!CHG)
USB5V: C4.1, C6.1, C8.1, C10.1, U2.1 (USB), U3.1 (USB), U4.1 (USB), U5.1 (USB); also elsewhere on the board

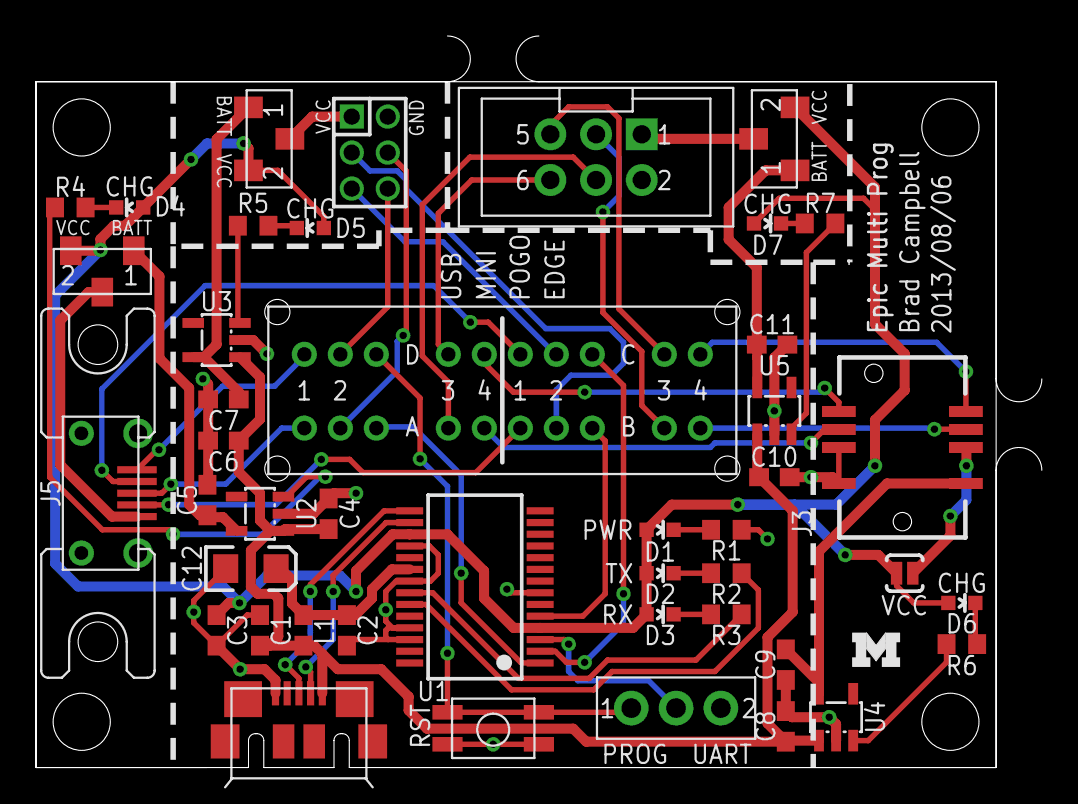
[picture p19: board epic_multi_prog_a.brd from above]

Board: 2 copper layers, 55.9 x 40.6 mm, 45 parts (0 on the bottom side), 48 nets.

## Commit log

2013-07-14 Start on the universal programmer board for epic
    [epic_multi_prog_a.brd, epic_multi_prog_a.sch]
2013-07-14 Test routing to see how this board is going to look
    [epic_multi_prog_a.brd, epic_multi_prog_a.sch]
2013-07-14 added power switches, moving things around
    [epic_multi_prog_a.brd, epic_multi_prog_a.sch]
2013-07-14 Moved uart/prog switch
    Planning on the huge smd micro usb
    [epic_multi_prog_a.brd, epic_multi_prog_a.sch]
2013-07-14 Moved ftdi circuit over to fill space
    [epic_multi_prog_a.brd]
2013-07-14 Nearly routed, added more max1555s
    Decided that each circuit should have its own charging led.
    [epic_multi_prog_a.brd, epic_multi_prog_a.sch]
2013-07-14 Cleaned up airwires
    Need to get the pinout for programming opo.
    [epic_multi_prog_a.brd]
2013-07-15 added bom
    [epic_multi_prog_a.brd, epic_multi_prog_a.sch, epic_multi_prog_a_bom.xls]
2013-07-22 added opo usb connection
    [epic_multi_prog_a.brd, epic_multi_prog_a.sch]
2013-07-22 added milling layer for pannelization
    [epic_multi_prog_a.brd, epic_multi_prog_a.sch]
2013-08-06 updated epic multi prog to ship
    Checked bom, double checked opo, changed date.
    [epic_multi_prog_a.brd, epic_multi_prog_a.sch, epic_multi_prog_a_bom.xls]
2013-09-04 new bom
    [epic_multi_prog_a_bom.xls]
2013-09-13 updated bom
    [epic_multi_prog_a_bom.xls]
2013-09-13 running eagle script
    [epic_multi_prog_a_bom.csv]
2013-10-02 new epic multip prog zip
    [epic_multi_prog_a_bom.csv]
2014-01-09 better doc for pcb

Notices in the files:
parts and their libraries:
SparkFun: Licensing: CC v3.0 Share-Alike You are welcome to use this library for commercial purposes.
